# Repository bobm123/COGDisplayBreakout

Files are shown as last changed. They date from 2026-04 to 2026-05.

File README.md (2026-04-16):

# COG Display Breakout

This is a breakout board for the **ERC12864FSF-11** COG (Chip On Glass) LCD module, a 0.96", 128x64 pixel display using an ST7567 controller and 4-wire SPI an interface. The PCB routes the display's inputs from its 12-pin FFC cable to a breadboard-friendly 2.54mm pin header. It also exposes the backlight LED pins and provides a few discrete components for LCD module.

It was designed to have a  form factor (~27x27mm, 4 mounting holes, pin headers) to like the Adafruit [0.96" OLED module](https://www.adafruit.com/product/326) and similar 1" displays.

LCD technology differs from the OLED displays commonly found on display boards of this size. LCD should be daylight readable like e-paper, but with simpler hardware and software requirements. However, LCDs may need a backlight in low-light conditions, so the breakout includes connections display's built-in LED with an option for always on operation. Contrast control is through software.

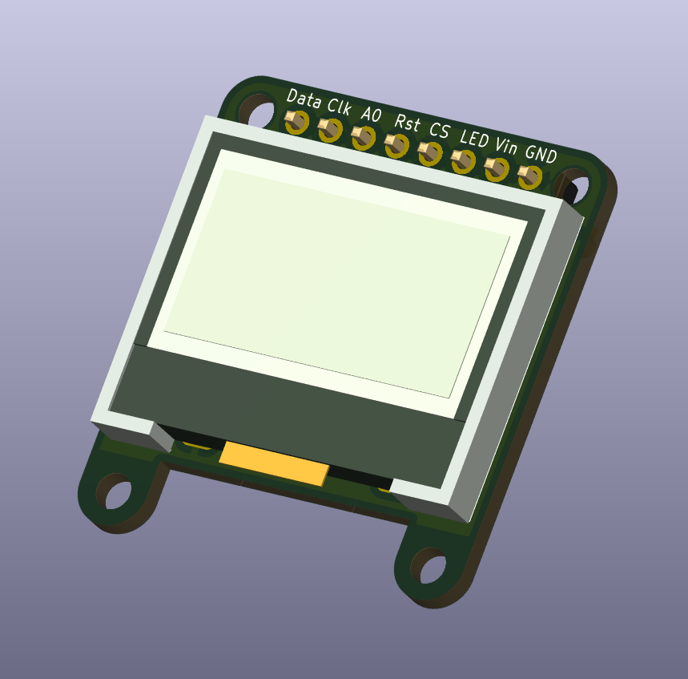
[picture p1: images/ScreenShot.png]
KiCad 3D render of the breakout board


## Specifications

| Parameter | Value |
|---|---|
| Display | [ERC12864FSF-11](https://www.buydisplay.com/0-96-inch-low-cost-white-128x64-graphic-cog-lcd-display-st7567-spi) (128x64, monochrome) |
| Controller | ST7567 |
| Interface | 4-wire SPI |
| Supply voltage | 3.3V only |
| Board size | ~27 x 27mm |
| Mounting | 4x M2 holes |

## Repository Structure

```
ArduinoCode/                             Example sketches for ESP32-C3
COGDisplayBreakout.pretty/               Custom footprint library
COGDisplayBreakout.3dmodels/             Custom 3D models
docs/                                    Datasheets, reference designs, tutorials
images/                                  Image assets
step/                                    3D models of the board and a small case
COGDisplayBreakout.kicad_sch             Schematic
COGDisplayBreakout.kicad_pcb             PCB layout
COGDisplayBreakout.kicad_sym             Custom symbol library
README.md
```

---

## Schematic and Board Layout

The KiCad 9 project files are at the repository root.

### Circuit Overview

The schematic connects the ERC12864FSF-11 display to an 8-pin SPI header (J1) with supporting passives:

**Header pinout (J1 - SPI_Header):**

| Pin | Signal | Description |
|-----|---|---|
| 1 | SDA | SPI data (MOSI) |
| 2 | SCL | SPI clock |
| 3 | A0 | Data/command select (DC) |
| 4 | /RST | Reset (active low) |
| 5 | /CS | Chip select (active low) |
| 6 | LED | LED control |
| 7 | VDD | +3.3V supply |
| 8 | GND | Ground |

**Passive components:**

| Ref | Value | Purpose |
|-----|---|---|
| R1 | 20R | Backlight LED current-limiting resistor |
| C1 | 10uF |  VDD bypass capacitor|
| C2 | 100nF | VDD bypass capacitor |
| C3 | 1uF | Charge pump capacitor (V0 to XV0) |
| C4 | 1uF | Charge pump capacitor (V0 to GND) |
| U1 | APX805S | Power-on reset IC for display /RST line |

The ST7567's built-in voltage booster generates the LCD bias voltage using external capacitors C3, and C4. No regulator or level shifting is included; the board is 3.3V only. Capacitors C1 and C2 are for decoupling. The R1 value was taken from the reference design, but for 10-20 mA LED current it should be about 200 Ohms.

The APX805S monitors VDD and holds the display /RST line low until power is stable, providing a clean power-on reset without requiring a GPIO pin from the host microcontroller. The /RST header pin (pin 4) is still available for external reset if needed.

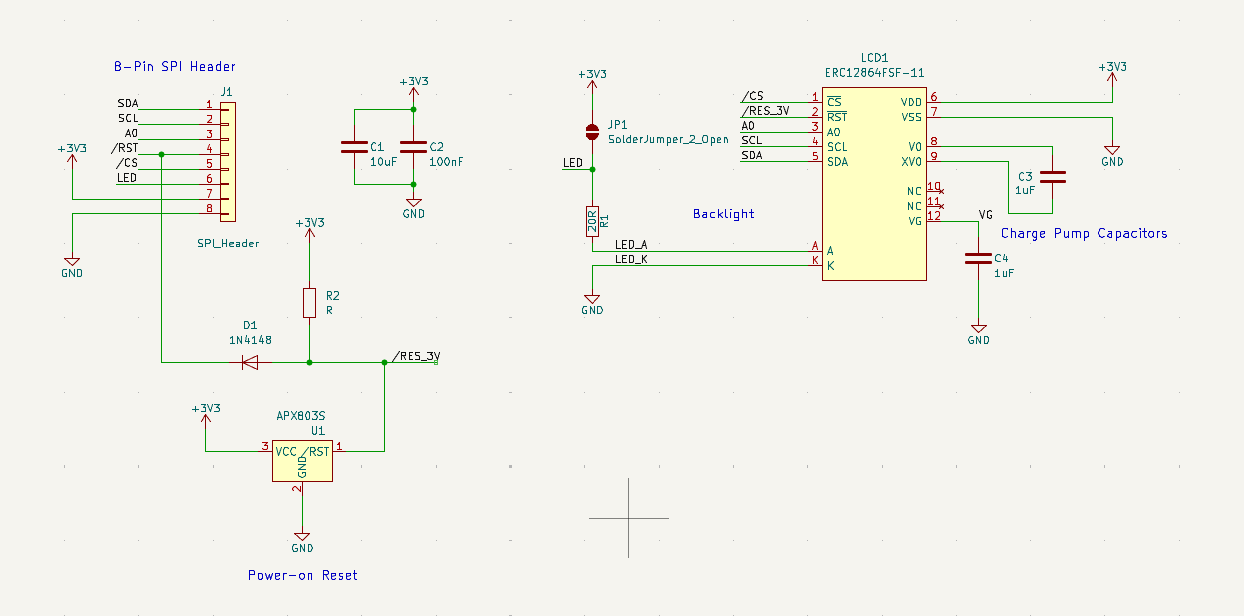
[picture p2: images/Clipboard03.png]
Breakout board schematic


### PCB

This is a 2-layer board, ~27x27mm. The display's 12-pin FFC cable (0.6mm pitch) is soldered directly to SMD pads on the back side. The display module mounts flat against the front by means of plastic mounting pins on the display case and the solder tabs for the backlight LED. Four M2 mounting holes at the corners matching similar OLED modules.

The display's 12-pin FFC cable is a non-standard 0.6mm pitch, so must be soldered directly to pads on the breakout PCB.

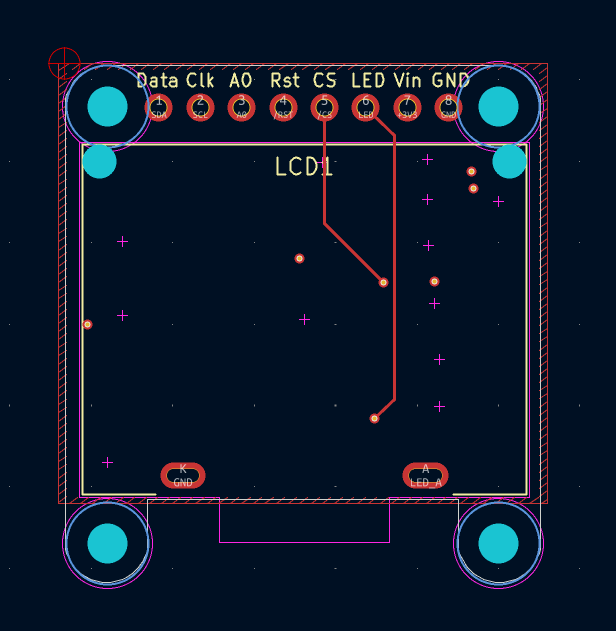
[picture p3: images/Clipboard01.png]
PCB - front

PCB Front (ground plane copper hidden)

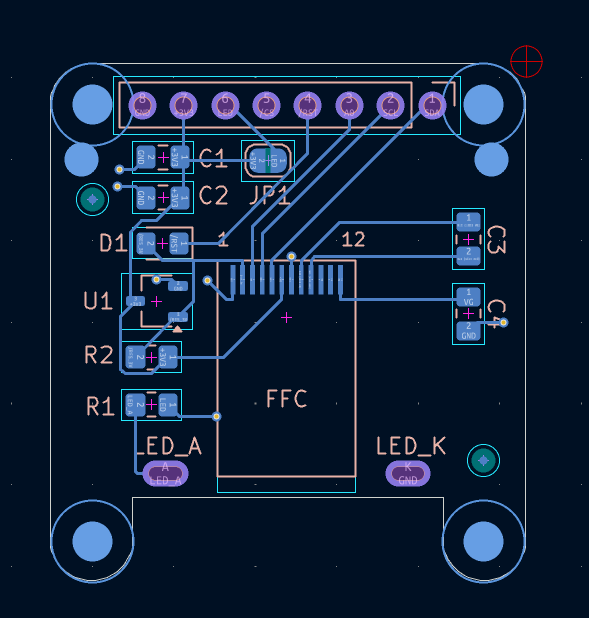
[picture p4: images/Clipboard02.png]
PCB - back

PCB Back

### Board Revisions

- **V0.1** (March 2026) - Initial prototype. Known issues: C1 wiring error, missing VG capacitor. See `AssemblyNotes.txt` for workarounds.

- **V0.2** (March 2026) - Fixed capacitor circuit. Known issue: backlight A/K pads swapped. See `AssemblyNotes.txt`.
Gerber files: V0.2 in `Gerbers20260323/`.

- **V1.0** (April 2026) - Fixed A/K pads and connected LED control to pin 6. See `AssemblyNotes.txt`.
Gerber files: V1.0 in `Gerbers20260403/`.

- **V1.1** (April 2026) - Added APX805S power-on reset IC for display /RST line. External reset connection via header pin 4 remains optional.
Gerbers sent to DigiKey RedBoard fab 2026-04-15.

---

## Custom ERC12864FSF-11 KiCad Library

The project includes a custom schematic symbol, PCB footprint, and 3D model for the ERC12864FSF-11 display module. These are in project-local libraries referenced via `sym-lib-table` and `fp-lib-table`.

### Schematic Symbol

**File:** `COGDisplayBreakout.kicad_sym`
**Symbol name:** `ERC12864FSF-11`

12-pin FFC cable (0.6mm pitch, 19mm long) plus 2 backlight pins.

| Pin | Name | Type | Description |
|-----|---|---|---|
| 1 | ~{CS} | Input | Chip select (active low) |
| 2 | ~{RST} | Input | Reset (active low) |
| 3 | A0 | Input | Data/command select |
| 4 | SCL | Input | SPI clock |
| 5 | SDA | Input | SPI data (MOSI) |
| 6 | VDD | Power | +3.3V supply |
| 7 | VSS | Power | Ground |
| 8 | V0 | Passive | Contrast voltage (booster output) |
| 9 | XV0 | Passive | Booster capacitor tap |
| 10 | NC | - | Not connected |
| 11 | NC | - | Not connected |
| 12 | VG | Passive | Negative voltage for LCD bias |
| A | A | Passive | Backlight LED anode |
| K | K | Passive | Backlight LED cathode |

Note: The backlight pins (A, K) are separate solder tabs on the display module, not part of the 12-pin FFC cable.

### PCB Footprint

**File:** `COGDisplayBreakout.pretty/ERC12864FSF-11_COG_LCD.kicad_mod`

There is a lot going on with this component's footprint:
- 12 SMD pads at 0.6mm pitch for direct-solder FFC cable connection
- Module outline on front silkscreen
- Back silkscreen shows how the FFC cable would wrap around
- 2 through-hole oval pads for backlight pins (A and K)
- Two NPT holes for case aliment studs
- An NPT oval slot to pass the FFC cable to the back of the PCB 

The 12 SMD pads are a bit longer to allow some play when wrapping the FFC cable around to the back. The pads and oval slot are positioned relative to the stud holes and backlight pins so the FFC cable end is centered on the pads. 

Unfortunately, there does not seem to be an FFC/FPC connector available in 12-pin, 6mm pitch so it must be soldered to the PCB. A piece of Kapton tape over the solder joins will provide a bit of strain relief and protection from shorts. 
  
### 3D Model

**Directory:** `COGDisplayBreakout.3dmodels/`

| File | Format | Description |
|---|---|---|
| `ERC12864FSF-11.step` | STEP | Solid body model for KiCad 3D viewer |
| `ERC12864FSF-11_COG_LCD.wrl` | VRML | Lightweight preview model |

The STEP model is referenced by the footprint and renders in KiCad's 3D viewer and to export the PCB with components as a 3D model.

---

## Arduino Code

Example sketches are in `ArduinoCode/`. The code should run on most modern Arduino board variants with sufficient pins and memory. The code currently targets the [**Adafruit QT Py ESP32-C3**](https://www.adafruit.com/product/5405) and uses the **U8g2** graphics library.

### Dependencies

- [U8g2](https://github.com/olikraus/u8g2) - Monochrome graphics library (handles ST7567 initialization, SPI transport, fonts, and drawing)
- SPI (built-in)

Install U8g2 via the Arduino IDE Library Manager.

### Pin Mapping (QT Py ESP32-C3 to breakout header)

| Display Signal | Header Pin | QT Py Pin | ESP32-C3 GPIO |
|---|---|---|---|
| SCL (clock) | 1 | SCK | 10 |
| SDA (data) | 2 | MO | 7 |
| A0 (DC) | 3 | MI* | 8 |
| /RST | 4 | APX805S on breakout | - |
| /CS | 5 | tied to GND | - |
| LED | 6 | A3 | - |
| GND | 1 | GND | - |
| VDD | 2 | 3V3 | - |

*The MISO pin is repurposed as GPIO since the ERC12864 does not provide data out.

### Sketches

Here are some Arduino sketches that can be run on a XIAO style board like Adafruit's QT Py ESP32-C3 with the connections shown above

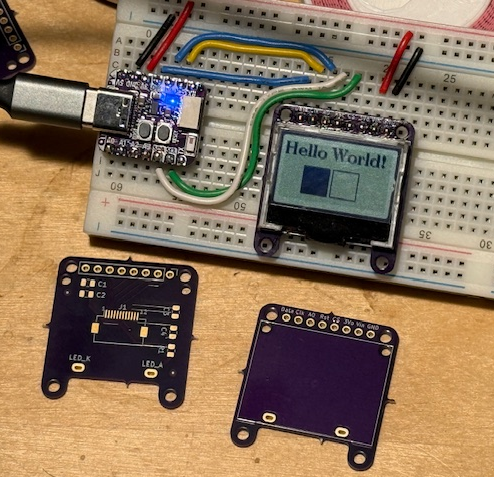
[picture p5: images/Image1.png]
Breadboard with QT Py ESP32-C3 and display running ERC12864_Hello


| Sketch | Description |
|---|---|
| `ERC12864_Hello/` | Minimal hello-world with text and simple graphics. Also blinks the QT Py's NeoPixel. |
| `ERC12864_SPIDemo/` | AI Port of the manufacturer's C tutorial. Cycles through text, graphics primitives, XBM bitmap, and test patterns. Includes commented-out contrast adjustment code for future button support. |
| `GraphicsTest/` | U8g2 graphics test suite (from the U8g2 examples, configured for this display). |
| `ScrollingText/` | U8g2 scrolling text demo (from the U8g2 examples, configured for this display). |

### U8g2 Constructor

All sketches use the same U8g2 constructor. Identifies the display module by part number and the SPI interface pins. See mappings above.

```cpp
U8G2_ST7565_ERC12864_ALT_F_4W_SW_SPI u8g2(U8G2_R0,
    /* clock=*/ 10, /* data=*/ 7, /* cs=*/ U8X8_PIN_NONE, /* dc=*/ 8, /* reset=*/ U8X8_PIN_NONE);
```

- `ERC12864_ALT` - contrast-improved variant for this display
- `_F_` - full framebuffer mode (~1KB RAM)
- `4W_SW_SPI` - 4-wire software SPI

The 4-wire HW variants of the U8g2 constructors are intended for the platform's native SPI interface: MOSI, MISO, clock and chip select. Since this device is write only the MISO pin is repurposed for A0 (Data/Command select). The 4-wire SW constructor is used to support this pin mapping but others are possible.

/CS is tied to GND on the breakout board, so the display is always selected and no GPIO is needed for chip select. If sharing the SPI bus with other devices, connect /CS to a GPIO pin and replace `U8X8_PIN_NONE` with that pin number in the constructor.

/RST is managed by the on-board APX805S power-on reset IC, so no GPIO is needed for reset. If external reset control is required, connect the /RST header pin to a GPIO and replace the reset `U8X8_PIN_NONE` with that pin number.

---

## Reference Documentation

Datasheets and reference material are in `docs/`:

- `ERC12864-11_Datasheet.pdf` - Display module datasheet
- `ST7567_V1.7.pdf` - Controller IC datasheet
- `ERC12864FSF-11_Display.md` - Display specifications summary
- `ERC12864FSF-11_SPI_Reference_Design.md` - Wiring guide and U8g2 examples
- `ERC12864-11_Tutorial/` - Manufacturer's C code tutorial and interface schematic

## Tools

- **KiCad 9** for schematic and PCB design
- **Arduino IDE** with ESP32 board support for firmware development
- **U8g2** library for display graphics

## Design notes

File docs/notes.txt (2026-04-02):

Link to .96 COG Display

Description

"ERC12864FSF-11 is 0.96 inch White background with 128x64 monochrome White pixels cog(chip on glass) lcd module,ST7567 controller,compact size,high contrast,wide operating temperature,wide view angle,white led backlight,fstn-lcd positive,fpc connection soldering type fpc connection,It supports 4-wire serial spi interface.

It's easily controlled by MCU such as 8051,PIC,AVR,ARDUINO,ARM and Raspberry Pi.It can be used in any embedded systems,industrial device,security,medical and hand-held equipment.

Of course, we wouldn't just leave you with a datasheet and a "good luck!".For 8051 microcontroller user,we prepared the detailed tutorial such as interfacing, demo code and Development Kit at the bottom of this page."

Black on White (on order):
https://www.buydisplay.com/0-96-inch-low-cost-white-128x64-graphic-cog-lcd-display-st7567-spi

White on Black:
https://www.buydisplay.com/0-96-inch-low-cost-black-128x64-graphic-cog-lcd-display-st7567-spi

White on Blue
https://www.buydisplay.com/0-96-inch-low-cost-blue-128x64-graphic-cog-lcd-display-st7567-spi

This will be fun for later, but they also have a SPI/I2C variant that might be more similar to
the Adafrui OLED units:
https://www.buydisplay.com/spi-small-0-96-inch-128x64-graphic-cog-lcd-display-module-for-smart-watch

See the ./ERC12864-10_Series/ directory for details
- has a 30 pin connector, needs bottom contact style connector
- slightly smaller case size
- can use 4-wire SPI or 2-wire I2C (TST5 pin to cuttable jumper)
- Backlight pins on ribbon cable

From Github U8g2 page:
https://github.com/olikraus/u8g2/wiki/u8x8setupcpp#st7567-erc12864

Controller "st7567", Display "erc12864"
U8X8_ST7567_ERC12864_4W_SW_SPI(clk, data, cs, dc [, reset])
U8X8_ST7567_ERC12864_4W_HW_SPI(cs, dc [, reset])
U8X8_ST7567_ERC12864_2ND_4W_HW_SPI(cs, dc [, reset])
U8X8_ST7567_ERC12864_3W_SW_SPI(clk, data, cs [, reset])
U8X8_ST7567_ERC12864_3W_HW_SPI(cs [, reset])
U8X8_ST7567_ERC12864_6800(d0, d1, d2, d3, d4, d5, d6, d7, enable, cs, dc [, reset])
U8X8_ST7567_ERC12864_8080(d0, d1, d2, d3, d4, d5, d6, d7, enable, cs, dc [, reset])

Actually, its the U8g2 library
U8G2_ST7565_ERC12864_ALT_1_4W_SW_SPI u8g2(U8G2_R0, /* clock=*/ 10, /* data=*/ 7, /* cs=*/ 6, /* dc=*/ 8, /* reset=*/ 5);

Docs
https://github.com/olikraus/u8g2/wiki/u8g2setupcpp#st7565-erc12864_alt
https://github.com/olikraus/u8g2/wiki/u8g2reference#carduino-example

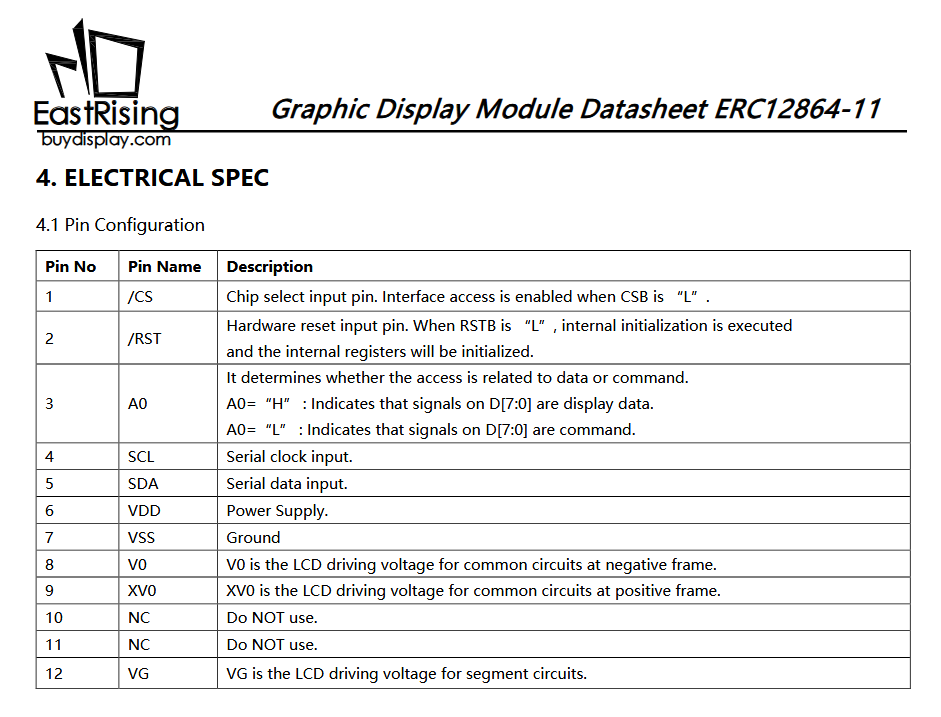
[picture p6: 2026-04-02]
docs/ERC12864-11-pinouts.png

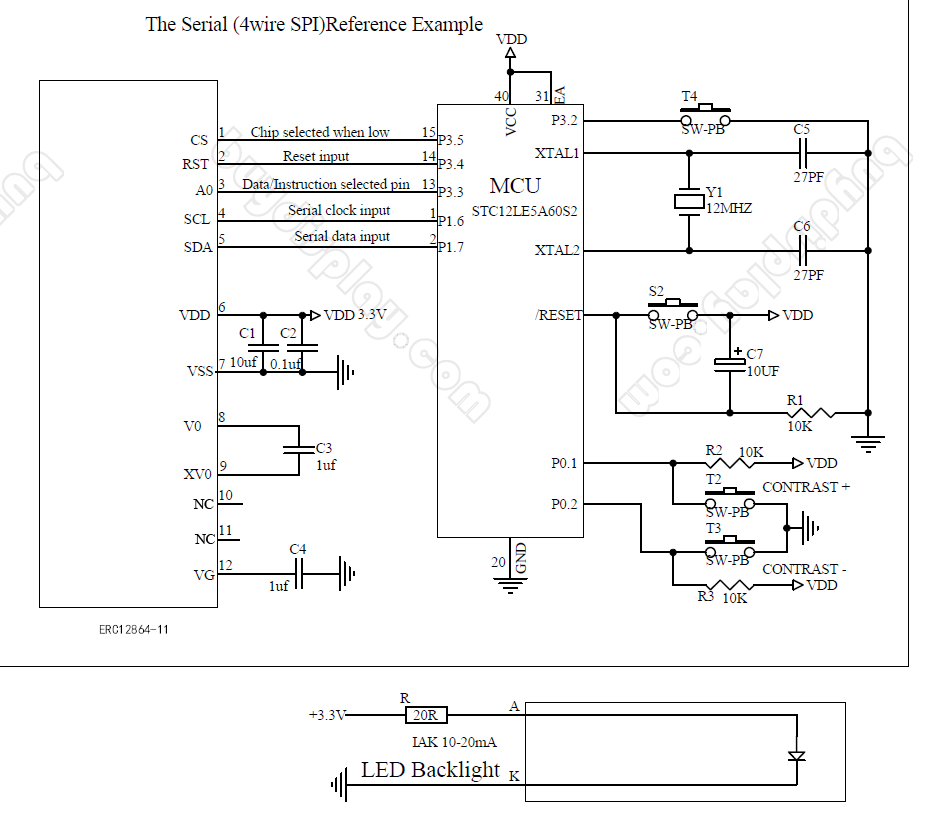
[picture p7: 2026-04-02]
docs/ERC12864-11_Tutorial/ReferenceDesign.png

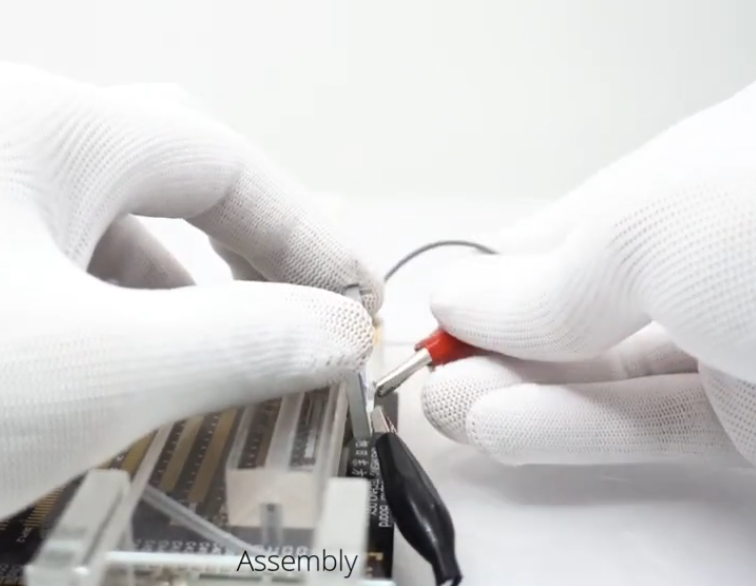
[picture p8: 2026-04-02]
docs/erc12864-11_LED_A_K.png

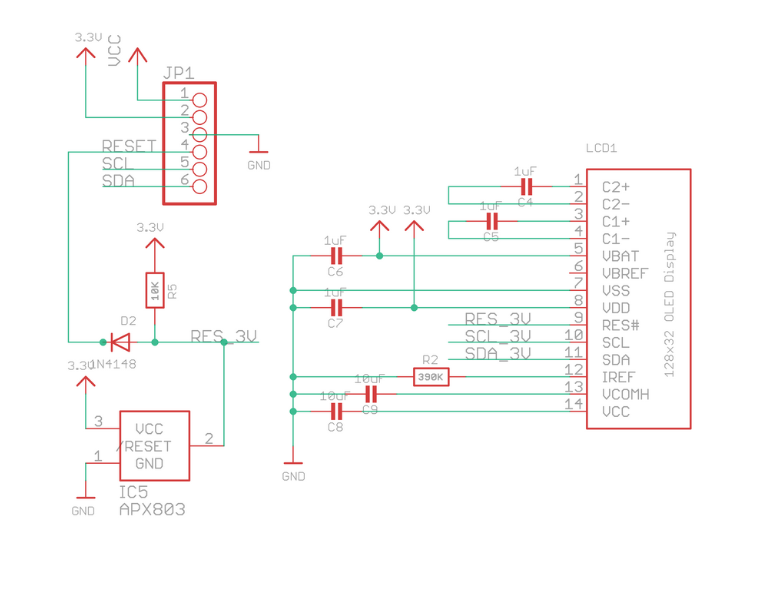
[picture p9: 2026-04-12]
docs/PO-ResetCircuit.png

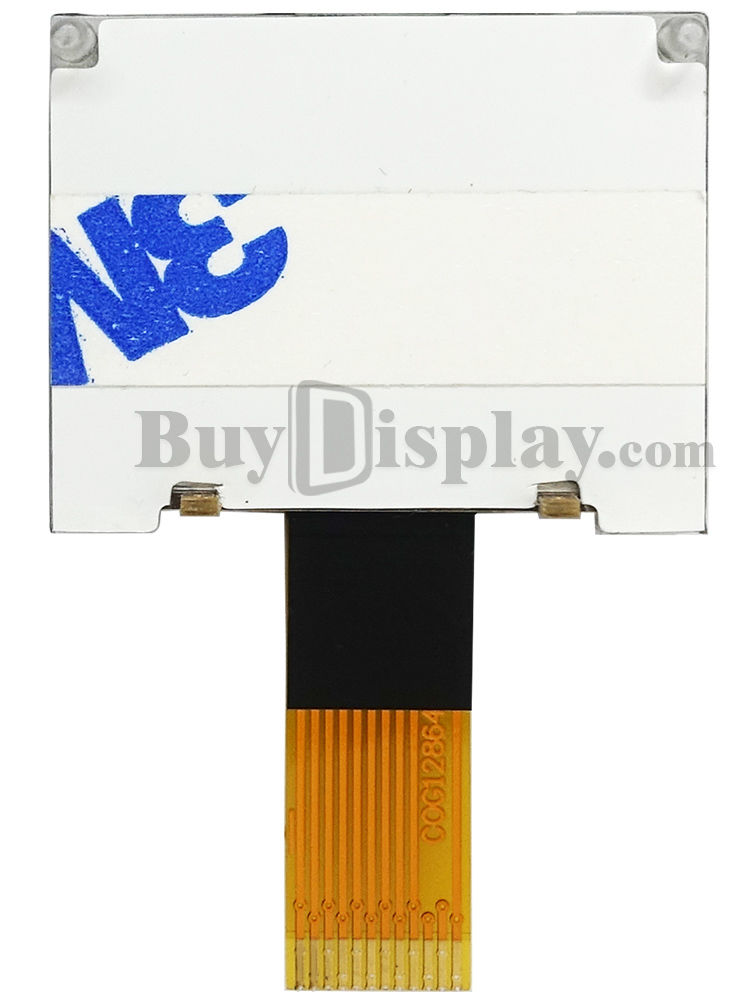
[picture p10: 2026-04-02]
docs/erc12864-11_backside.png

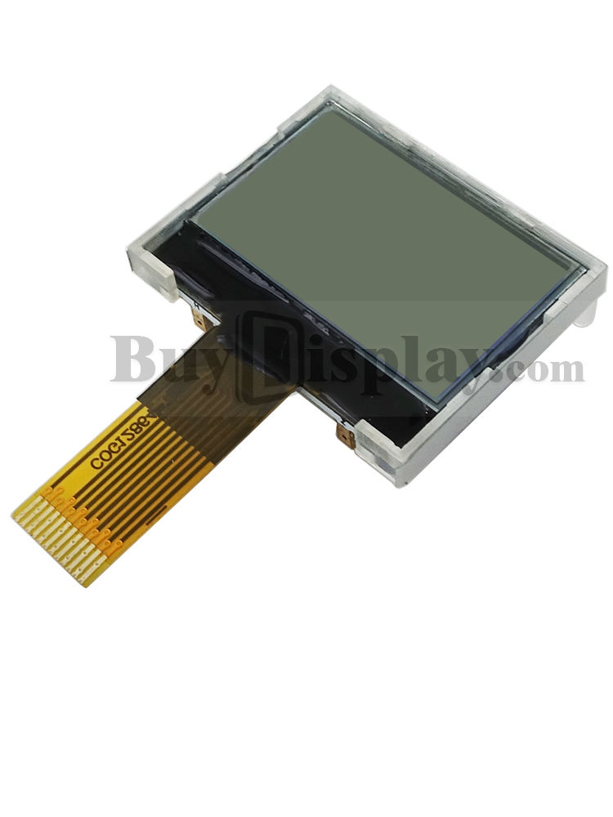
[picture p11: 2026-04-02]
docs/erc12864fsf-front.png

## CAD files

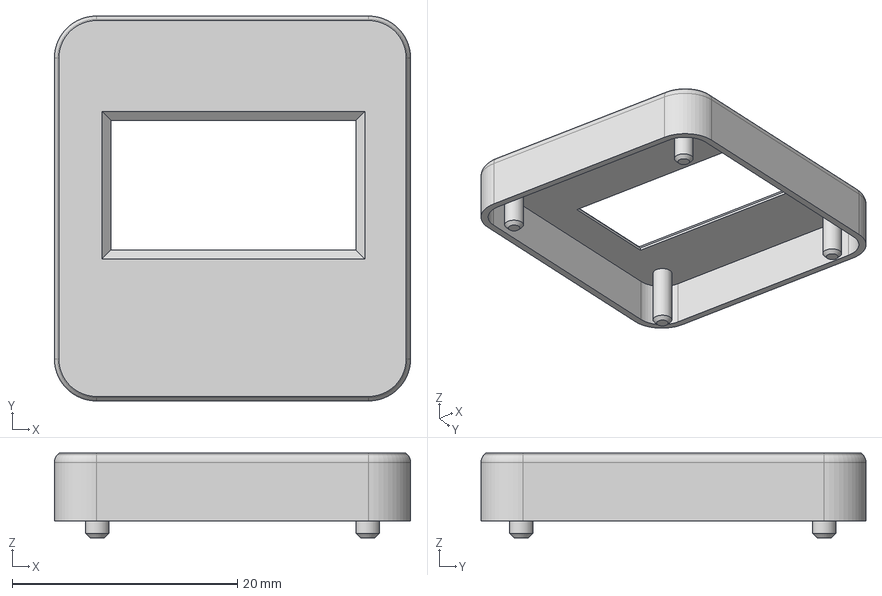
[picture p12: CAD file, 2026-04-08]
step/COGDisplayBreakout-Bezel.step
31.6 x 34.1 x 7.50 mm

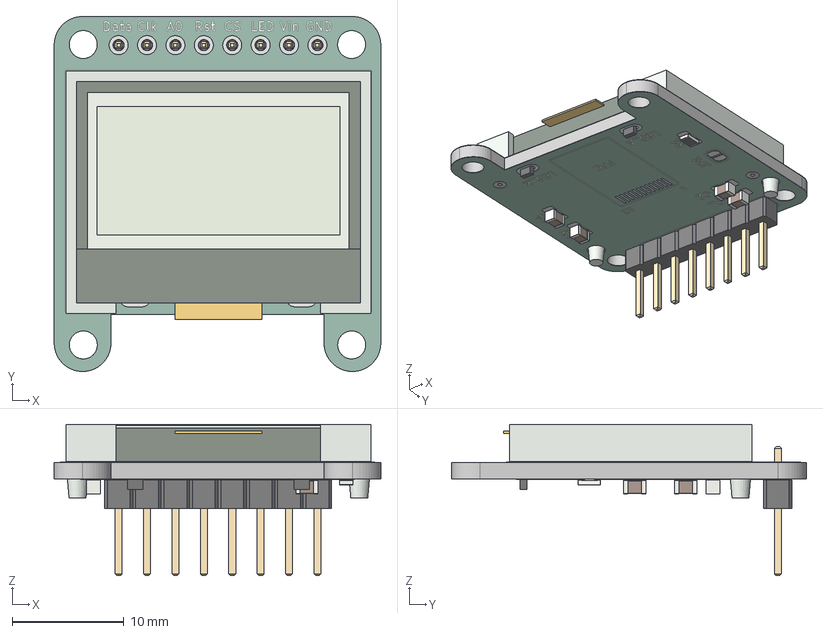
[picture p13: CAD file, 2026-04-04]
step/COGDisplayBreakout.step
29.2 x 31.8 x 13.5 mm
ERC12864FSF-11
C_0805_2012Metric x 4
PinHeader_1x08_P2.54mm_Vertical
R_0805_2012Metric
COGDisplayBreakout_copper
COGDisplayBreakout_pad
COGDisplayBreakout_via
COGDisplayBreakout_silkscreen x 2
COGDisplayBreakout_soldermask x 2
COGDisplayBreakout_PCB

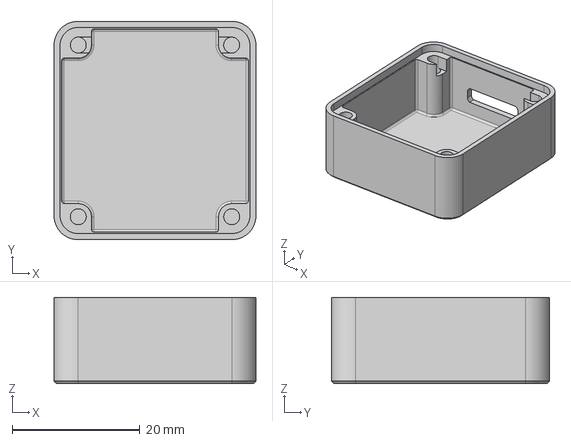
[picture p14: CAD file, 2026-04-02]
step/COGDisplayBreakout-Case.step
31.6 x 34.1 x 13.5 mm

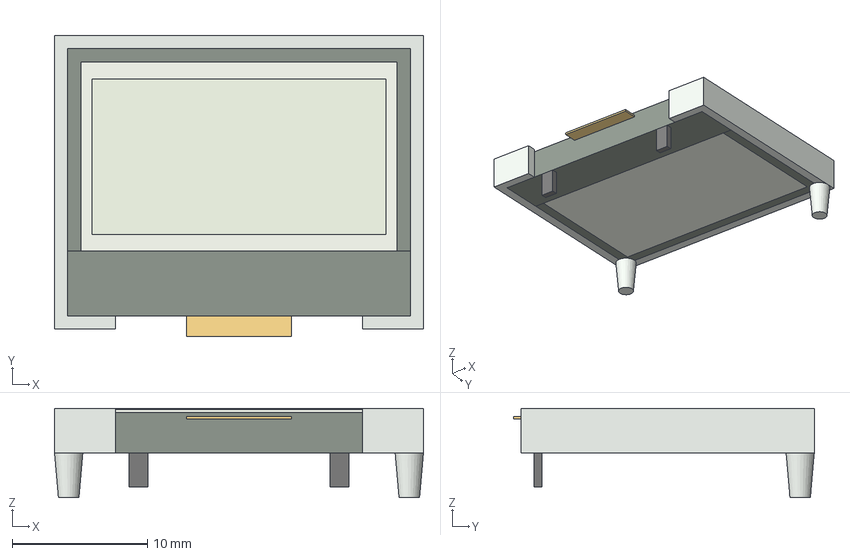
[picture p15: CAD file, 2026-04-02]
COGDisplayBreakout.3dmodels/ERC12864FSF-11.step
27.3 x 22.2 x 6.60 mm

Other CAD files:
step/COGDisplayBreakout-Bezel.stl

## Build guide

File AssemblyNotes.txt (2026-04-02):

Notes on V0.1 board sent to Fab on 3/3/2026
- Error in schematic has C1 (1uf) from V0 to ground. Leave this unpopulated
- Should have a second cap across 3.3 and gnd. C3/100nF is ok. if possible add a 10uF somewhere
- VG (currently unconnected, pin12 on connector) should have a 1uF cap to ground.
  -- possible remedy: 
    1) cut trace between C1 and C2. 
    2) cut trace From V0 to C2 pin 1 
    3) reconnect C2 pin 1 connector pin 12 (VG) with white wire  
- Same layout also sent to pcbway, back about the same time as oshpark board
- both board have wrong connector pitch! Unusable, D'oh!

Notes on V0.2 board, sent to Fab on 3/23/2026
- K and A swapped, avoid placing the resister
- Try bending tabs and insulate top 
- or file back the board and blue wire w/ 200R
- Should have used hand solder 0805 pads
- unconnected 3Vo pin, consider using this for LED on/off 
- check for an extra GND connection at V0 or VX0
- consider changing the 3Vo pin (unused) to a LED on function

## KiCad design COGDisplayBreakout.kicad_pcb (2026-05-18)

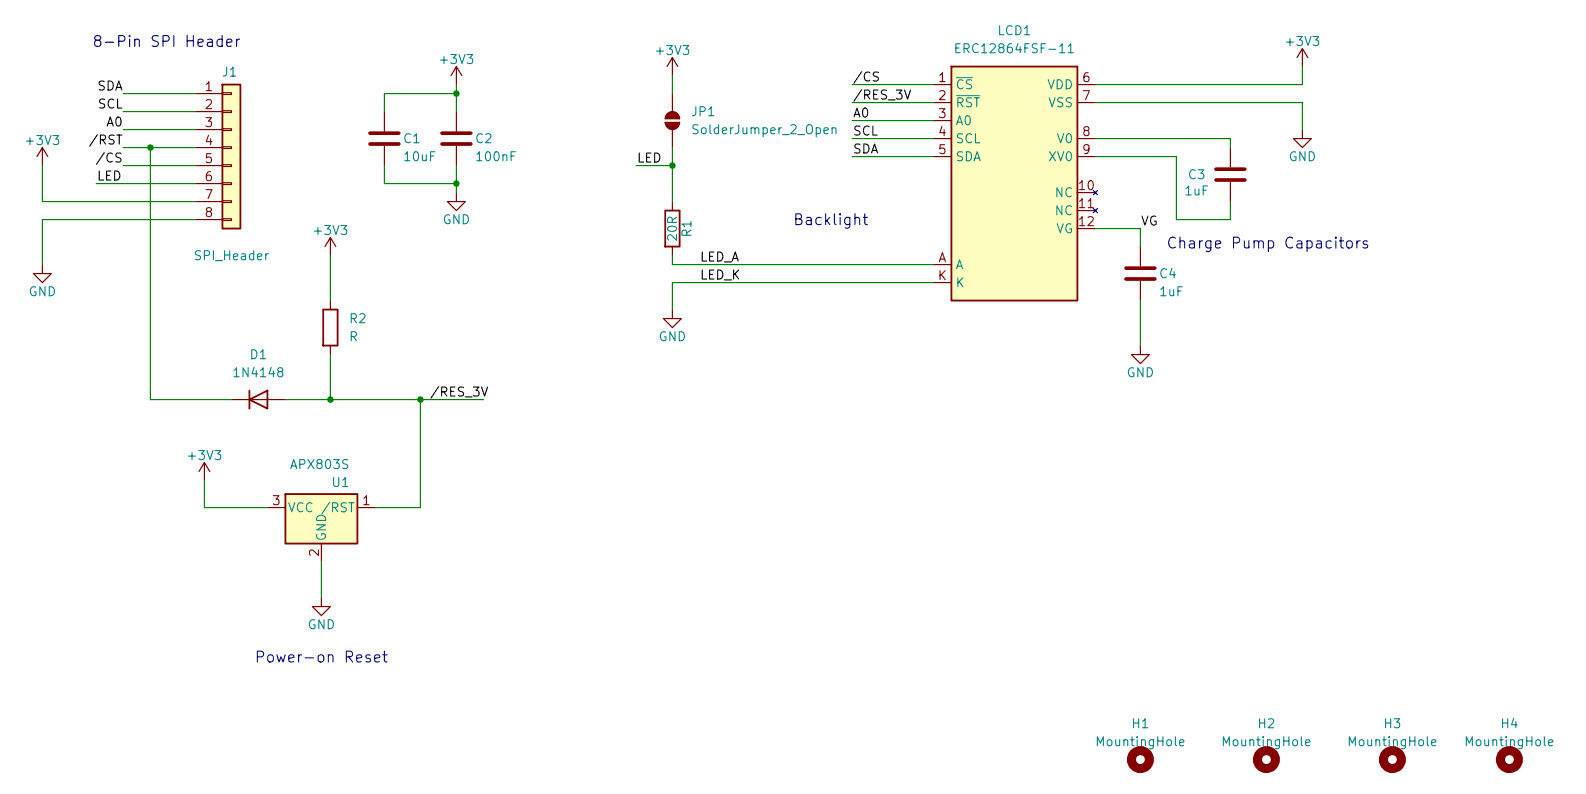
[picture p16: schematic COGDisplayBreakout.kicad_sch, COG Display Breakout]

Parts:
C1: 10uF; C_0805_2012Metric_Pad1.18x1.45mm_HandSolder
C2: 100nF; C_0805_2012Metric_Pad1.18x1.45mm_HandSolder
C3, C4: 1uF; C_0805_2012Metric_Pad1.18x1.45mm_HandSolder
D1: 1N4148; D_0805_2012Metric_Pad1.15x1.40mm_HandSolder
H1, H2, H3, H4: MountingHole; MountingHole_2.5mm
J1: SPI_Header; PinHeader_1x08_P2.54mm_Vertical
JP1: SolderJumper_2_Open; SolderJumper-2_P1.3mm_Open_RoundedPad1.0x1.5mm
LCD1: ERC12864FSF-11; ERC12864FSF-11_COG_LCD
R1: 20R; R_0805_2012Metric_Pad1.20x1.40mm_HandSolder
R2: R; R_0805_2012Metric_Pad1.20x1.40mm_HandSolder
U1: APX803S; TSOT-23

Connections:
+3V3: C1.1, C2.1, J1.7, JP1.2 (B), LCD1.6 (VDD), R2.1, U1.3 (VCC)
/A0: J1.3, LCD1.3 (A0)
/LED: J1.6, JP1.1 (A), R1.1
/LED_A: LCD1.A, R1.2
/SCL: J1.2, LCD1.4 (SCL)
/SDA: J1.1, LCD1.5 (SDA)
/VG: C4.1, LCD1.12 (VG)
//CS: J1.5, LCD1.1 (~CS)
//RES_3V: D1.2 (A), LCD1.2 (~RST), R2.2, U1.1 (/RST)
//RST: D1.1 (K), J1.4
GND: C1.2, C2.2, C4.2, J1.8, LCD1.7 (VSS), LCD1.K, U1.2 (GND)
unnamed: C3.1, LCD1.8 (V0)
unnamed: C3.2, LCD1.9 (XV0)

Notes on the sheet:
Charge Pump Capacitors
8-Pin SPI Header
Backlight
Power-on Reset

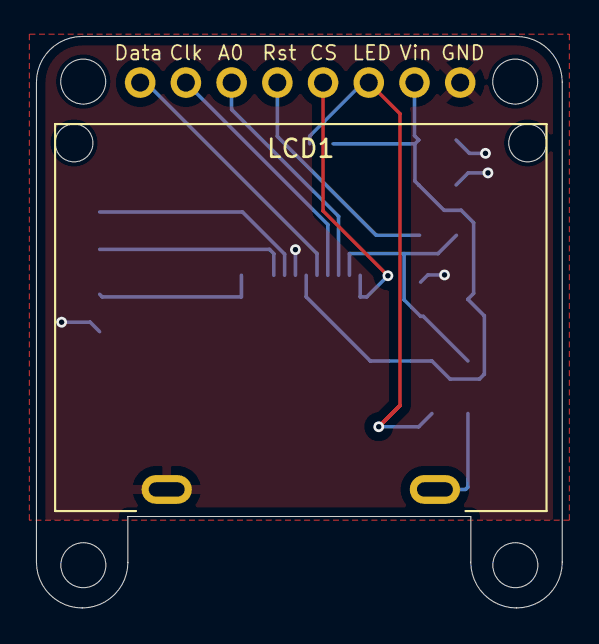
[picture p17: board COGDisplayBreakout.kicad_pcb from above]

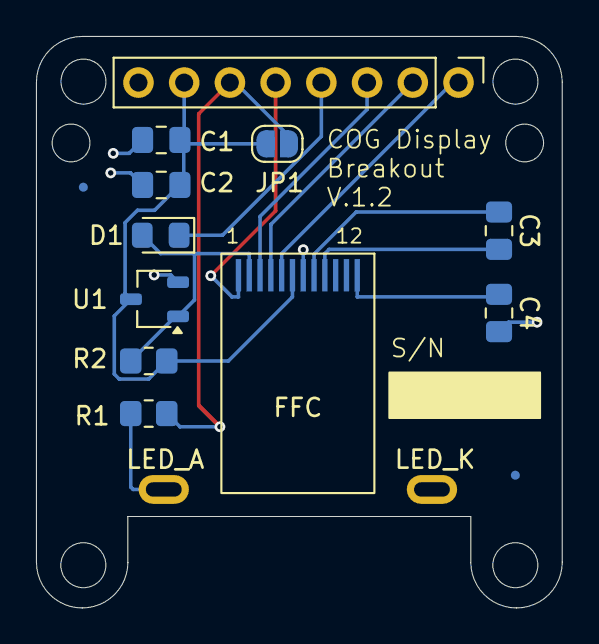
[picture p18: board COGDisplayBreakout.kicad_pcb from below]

Board: 2 copper layers, 29.2 x 31.8 mm, 17 parts (12 on the bottom side), 13 nets.

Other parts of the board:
FID1, FID2: FIDUCIAL""; Fiducial_0.5mm_Mask1.5mm

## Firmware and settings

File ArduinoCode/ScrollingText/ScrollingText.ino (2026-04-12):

/*

  ScrollingText.ino

  This will scroll text on the display. 
  Enable U8g2 16 bit mode (see FAQ) for larger text!

  Universal 8bit Graphics Library (https://github.com/olikraus/u8g2/)

  Copyright (c) 2016, olikraus@gmail.com
  All rights reserved.

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
  THIS SOFTWARE IS PROVIDED BY THE COPYRIGHT HOLDERS AND 
  CONTRIBUTORS "AS IS" AND ANY EXPRESS OR IMPLIED WARRANTIES, 
  INCLUDING, BUT NOT LIMITED TO, THE IMPLIED WARRANTIES OF 
  MERCHANTABILITY AND FITNESS FOR A PARTICULAR PURPOSE ARE 
  DISCLAIMED. IN NO EVENT SHALL THE COPYRIGHT HOLDER OR 
  CONTRIBUTORS BE LIABLE FOR ANY DIRECT, INDIRECT, INCIDENTAL, 
  SPECIAL, EXEMPLARY, OR CONSEQUENTIAL DAMAGES (INCLUDING, BUT 
  NOT LIMITED TO, PROCUREMENT OF SUBSTITUTE GOODS OR SERVICES; 
  LOSS OF USE, DATA, OR PROFITS; OR BUSINESS INTERRUPTION) HOWEVER 
  CAUSED AND ON ANY THEORY OF LIABILITY, WHETHER IN CONTRACT, 
  STRICT LIABILITY, OR TORT (INCLUDING NEGLIGENCE OR OTHERWISE) 
  ARISING IN ANY WAY OUT OF THE USE OF THIS SOFTWARE, EVEN IF 
  ADVISED OF THE POSSIBILITY OF SUCH DAMAGE.  

*/

#include <Arduino.h>
#include <U8g2lib.h>

#ifdef U8X8_HAVE_HW_SPI
#include <SPI.h>
#endif
#ifdef U8X8_HAVE_HW_I2C
#include <Wire.h>
#endif


/*
  U82glib Example Overview:
    Frame Buffer Examples: clearBuffer/sendBuffer. Fast, but may not work with all Arduino boards because of RAM consumption
    Page Buffer Examples: firstPage/nextPage. Less RAM usage, should work with all Arduino boards.
    U8x8 Text Only Example: No RAM usage, direct communication with display controller. No graphics, 8x8 Text only.
    
  This is a page buffer example.
  
*/

// Please UNCOMMENT one of the contructor lines below
// U8g2 Contructor List (Picture Loop Page Buffer)
// The complete list is available here: https://github.com/olikraus/u8g2/wiki/u8g2setupcpp
// Please update the pin numbers according to your setup. Use U8X8_PIN_NONE if the reset pin is not connected
// /CS is tied to GND on the breakout board (display always selected).
// If sharing the SPI bus with other devices, connect /CS to a GPIO and replace U8X8_PIN_NONE.
U8G2_ST7565_ERC12864_ALT_F_4W_SW_SPI u8g2(U8G2_R0, /* clock=*/ 10, /* data=*/ 7, /* cs=*/ U8X8_PIN_NONE, /* dc=*/ 8, /* reset=*/ 5);
//U8G2_NULL u8g2(U8G2_R0);	// null device, a 8x8 pixel display which does nothing
//U8G2_SSD1306_128X64_NONAME_1_4W_SW_SPI u8g2(U8G2_R0, /* clock=*/ 13, /* data=*/ 11, /* cs=*/ 10, /* dc=*/ 9, /* reset=*/ 8);
//U8G2_SSD1306_128X64_NONAME_1_4W_HW_SPI u8g2(U8G2_R0, /* cs=*/ 12, /* dc=*/ 4, /* reset=*/ 6);	// Arduboy (Production, Kickstarter Edition)
//U8G2_SSD1306_128X64_NONAME_1_4W_HW_SPI u8g2(U8G2_R0, /* cs=*/ 10, /* dc=*/ 9, /* reset=*/ 8);
//U8G2_SSD1306_128X64_NONAME_1_3W_SW_SPI u8g2(U8G2_R0, /* clock=*/ 13, /* data=*/ 11, /* cs=*/ 10, /* reset=*/ 8);
//U8G2_SSD1306_128X64_NONAME_1_3W_HW_SPI u8g2(U8G2_R0, /* cs=*/ 10, /* reset=*/ 8);
//U8G2_SSD1306_128X64_NONAME_1_HW_I2C u8g2(U8G2_R0, /* reset=*/ U8X8_PIN_NONE);
//U8G2_SSD1306_128X64_ALT0_1_HW_I2C u8g2(U8G2_R0, /* reset=*/ U8X8_PIN_NONE);   // same as the NONAME variant, but may solve the "every 2nd line skipped" problem
//U8G2_SSD1306_128X64_NONAME_1_SW_I2C u8g2(U8G2_R0, /* clock=*/ 13, /* data=*/ 11, /* reset=*/ 8);
//U8G2_SSD1306_128X64_NONAME_1_SW_I2C u8g2(U8G2_R0, /* clock=*/ SCL, /* data=*/ SDA, /* reset=*/ U8X8_PIN_NONE);   // All Boards without Reset of the Display
//U8G2_SSD1306_128X64_NONAME_1_SW_I2C u8g2(U8G2_R0, /* clock=*/ 16, /* data=*/ 17, /* reset=*/ U8X8_PIN_NONE);   // ESP32 Thing, pure SW emulated I2C
//U8G2_SSD1306_128X64_NONAME_1_HW_I2C u8g2(U8G2_R0, /* reset=*/ U8X8_PIN_NONE, /* clock=*/ 16, /* data=*/ 17);   // ESP32 Thing, HW I2C with pin remapping
//U8G2_SSD1306_128X64_NONAME_1_6800 u8g2(U8G2_R0, 13, 11, 2, 3, 4, 5, 6, A4, /*enable=*/ 7, /*cs=*/ 10, /*dc=*/ 9, /*reset=*/ 8);
//U8G2_SSD1306_128X64_NONAME_1_8080 u8g2(U8G2_R0, 13, 11, 2, 3, 4, 5, 6, A4, /*enable=*/ 7, /*cs=*/ 10, /*dc=*/ 9, /*reset=*/ 8);
//U8G2_SSD1306_128X64_VCOMH0_1_4W_HW_SPI u8g2(U8G2_R0, /* cs=*/ 10, /* dc=*/ 9, /* reset=*/ 8);	// same as the NONAME variant, but maximizes setContrast() range
//U8G2_SSD1306_128X64_ALT0_1_4W_HW_SPI u8g2(U8G2_R0, /* cs=*/ 10, /* dc=*/ 9, /* reset=*/ 8);	// same as the NONAME variant, but may solve the "every 2nd line skipped" problem
//U8G2_SSD1306_102X64_EA_OLEDS102_1_4W_HW_SPI u8g2(U8G2_R0, /* cs=*/ 10, /* dc=*/ 9, /* reset=*/ 8);	// same as the NONAME variant, but may solve the "every 2nd line skipped" problem
//U8G2_SSD1312_128X64_NONAME_1_4W_SW_SPI u8g2(U8G2_R0, /* clock=*/ 13, /* data=*/ 11, /* cs=*/ 10, /* dc=*/ 9, /* reset=*/ 8);
//U8G2_SSD1312_128X64_NONAME_1_SW_I2C u8g2(U8G2_R0, /* clock=*/ SCL, /* data=*/ SDA, /* reset=*/ 8);
//U8G2_SSD1312_128X64_NONAME_1_HW_I2C u8g2(U8G2_R0, /* reset=*/ 8);
//U8G2_SSD1312_120X28_1_4W_SW_SPI u8g2(U8G2_R0, /* clock=*/ 13, /* data=*/ 11, /* cs=*/ 10, /* dc=*/ 9, /* reset=*/ 8);
//U8G2_SSD1312_120X28_1_SW_I2C u8g2(U8G2_R0, /* clock=*/ SCL, /* data=*/ SDA, /* reset=*/ 8);
//U8G2_SSD1312_120X28_1_HW_I2C u8g2(U8G2_R0, /* reset=*/ 8);
//U8G2_SH1106_128X64_NONAME_1_4W_HW_SPI u8g2(U8G2_R0, /* cs=*/ 10, /* dc=*/ 9, /* reset=*/ 8);
//U8G2_SH1106_128X64_NONAME_1_HW_I2C u8g2(U8G2_R0, /* reset=*/ U8X8_PIN_NONE);
//U8G2_SH1106_128X64_VCOMH0_1_4W_HW_SPI u8g2(U8G2_R0, /* cs=*/ 10, /* dc=*/ 9, /* reset=*/ 8);		// same as the NONAME variant, but maximizes setContrast() range
//U8G2_SH1106_128X64_WINSTAR_1_4W_HW_SPI u8g2(U8G2_R0, /* cs=*/ 10, /* dc=*/ 9, /* reset=*/ 8);		// same as the NONAME variant, but uses updated SH1106 init sequence
//U8G2_SH1106_128X32_VISIONOX_1_HW_I2C u8g2(U8G2_R0, /* reset=*/ U8X8_PIN_NONE); 
//U8G2_SH1106_128X32_VISIONOX_1_4W_HW_SPI u8g2(U8G2_R0, /* cs=*/ 10, /* dc=*/ 9, /* reset=*/ 8);
//U8G2_SH1106_72X40_WISE_1_4W_HW_SPI u8g2(U8G2_R0, /* cs=*/ 10, /* dc=*/ 9, /* reset=*/ 8);
//U8G2_SH1107_64X128_1_4W_HW_SPI u8g2(U8G2_R0, /* cs=*/ 10, /* dc=*/ 9, /* reset=*/ 8);
//U8G2_SH1107_128X128_1_4W_HW_SPI u8g2(U8G2_R0, /* cs=*/ 10, /* dc=*/ 9, /* reset=*/ 8);
//U8G2_SH1107_128X128_1_HW_I2C u8g2(U8G2_R0, /* reset=*/ 8);
//U8G2_SH1107_128X80_1_HW_I2C u8g2(U8G2_R0, /* reset=*/ 8);
//U8G2_SH1107_PIMORONI_128X128_1_HW_I2C u8g2(U8G2_R0, /* reset=*/ 8);
//U8G2_SH1107_SEEED_128X128_1_SW_I2C u8g2(U8G2_R0, /* clock=*/ SCL, /* data=*/ SDA, /* reset=*/ U8X8_PIN_NONE);
//U8G2_SH1107_SEEED_128X128_1_HW_I2C u8g2(U8G2_R0, /* reset=*/ U8X8_PIN_NONE);
//U8G2_SH1107_SEEED_96X96_1_4W_HW_SPI u8g2(U8G2_R0, /* cs=*/ 10, /* dc=*/ 9, /* reset=*/ 8);
//U8G2_SH1107_HJR_OEL1M0201_96X96_1_4W_HW_SPI u8g2(U8G2_R0, /* cs=*/ 10, /* dc=*/ 9, /* reset=*/ 8);
//U8G2_SH1107_TK078F288_80X128_1_4W_HW_SPI u8g2(U8G2_R0, /* cs=*/ 10, /* dc=*/ 9, /* reset=*/ 8);
//U8G2_SH1108_128X160_1_4W_HW_SPI u8g2(U8G2_R0, /* cs=*/ 10, /* dc=*/ 9, /* reset=*/ 8);
//U8G2_CH1120_128X160_1_4W_HW_SPI u8g2(U8G2_R0, /* cs=*/ 10, /* dc=*/ 9, /* reset=*/ 8);
//U8G2_SH1108_160X160_1_4W_HW_SPI u8g2(U8G2_R0, /* cs=*/ 10, /* dc=*/ 9, /* reset=*/ 8);
//U8G2_SH1122_256X64_1_4W_HW_SPI u8g2(U8G2_R0, /* cs=*/ 10, /* dc=*/ 9, /* reset=*/ 8);				// Enable U8G2_16BIT in u8g2.h
//U8G2_SH1122_256X64_1_4W_SW_SPI u8g2(U8G2_R0, /* clock=*/ 13, /* data=*/ 11, /* cs=*/ 10, /* dc=*/ 9, /* reset=*/ 8);        // Enable U8G2_16BIT in u8g2.h
//U8G2_SSD1306_128X32_UNIVISION_1_SW_I2C u8g2(U8G2_R0, /* clock=*/ 21, /* data=*/ 20, /* reset=*/ U8X8_PIN_NONE);   // Adafruit Feather M0 Basic Proto + FeatherWing OLED
//U8G2_SSD1306_128X32_UNIVISION_1_SW_I2C u8g2(U8G2_R0, /* clock=*/ SCL, /* data=*/ SDA, /* reset=*/ U8X8_PIN_NONE);   // Adafruit Feather ESP8266/32u4 Boards + FeatherWing OLED
//U8G2_SSD1306_128X32_UNIVISION_1_HW_I2C u8g2(U8G2_R0, /* reset=*/ U8X8_PIN_NONE);   // Adafruit ESP8266/32u4/ARM Boards + FeatherWing OLED
//U8G2_SSD1306_128X32_UNIVISION_1_HW_I2C u8g2(U8G2_R0, /* reset=*/ U8X8_PIN_NONE, /* clock=*/ SCL, /* data=*/ SDA);   // pin remapping with ESP8266 HW I2C
//U8G2_SSD1306_128X32_WINSTAR_1_HW_I2C u8g2(U8G2_R0, /* reset=*/ U8X8_PIN_NONE, /* clock=*/ SCL, /* data=*/ SDA);   // pin remapping with ESP8266 HW I2C
//U8G2_SSD1306_64X48_ER_1_HW_I2C u8g2(U8G2_R0, /* reset=*/ U8X8_PIN_NONE);   // EastRising 0.66" OLED breakout board, Uno: A4=SDA, A5=SCL, 5V powered
//U8G2_SSD1306_48X64_WINSTAR_1_HW_I2C u8g2(U8G2_R0, /* reset=*/ U8X8_PIN_NONE);   
//U8G2_SSD1306_64X32_NONAME_1_HW_I2C u8g2(U8G2_R0, /* reset=*/ U8X8_PIN_NONE);
//U8G2_SSD1306_64X32_1F_1_HW_I2C u8g2(U8G2_R0, /* reset=*/ U8X8_PIN_NONE);
//U8G2_SSD1306_96X16_ER_1_HW_I2C u8g2(U8G2_R0, /* reset=*/ U8X8_PIN_NONE);   // EastRising 0.69" OLED 
//U8G2_SSD1306_72X40_ER_1_HW_I2C u8g2(U8G2_R0, /* reset=*/ U8X8_PIN_NONE);   // EastRising 0.42" OLED 
//U8G2_SSD1306_96X40_1_HW_I2C u8g2(U8G2_R0, /* reset=*/ U8X8_PIN_NONE);
//U8G2_SSD1306_96X39_1_HW_I2C u8g2(U8G2_R0, /* reset=*/ U8X8_PIN_NONE);
//U8G2_SSD1322_240X128_1_4W_SW_SPI u8g2(U8G2_R0, /* clock=*/ 13, /* data=*/ 11, /* cs=*/ 10, /* dc=*/ 9, /* reset=*/ 8);
//U8G2_SSD1322_TOPWIN_240X128_1_4W_SW_SPI u8g2(U8G2_R0, /* clock=*/ 13, /* data=*/ 11, /* cs=*/ 10, /* dc=*/ 9, /* reset=*/ 8);
//U8G2_SSD1322_NHD_256X64_1_4W_SW_SPI u8g2(U8G2_R0, /* clock=*/ 13, /* data=*/ 11, /* cs=*/ 10, /* dc=*/ 9, /* reset=*/ 8);	// Enable U8G2_16BIT in u8g2.h
//U8G2_SSD1322_NHD_256X64_1_4W_HW_SPI u8g2(U8G2_R0, /* cs=*/ 10, /* dc=*/ 9, /* reset=*/ 8);	// Enable U8G2_16BIT in u8g2.h
//U8G2_SSD1322_ZJY_256X64_1_4W_SW_SPI u8g2(U8G2_R0, /* clock=*/ 13, /* data=*/ 11, /* cs=*/ 10, /* dc=*/ 9, /* reset=*/ 8);	// Enable U8G2_16BIT in u8g2.h
//U8G2_SSD1322_ZJY_256X64_1_4W_HW_SPI u8g2(U8G2_R0, /* cs=*/ 10, /* dc=*/ 9, /* reset=*/ 8);	// Enable U8G2_16BIT in u8g2.h
//U8G2_SSD1362_256X64_1_4W_SW_SPI u8g2(U8G2_R0, /* clock=*/ 13, /* data=*/ 11, /* cs=*/ 10, /* dc=*/ 9, /* reset=*/ 8);	// Enable U8G2_16BIT in u8g2.h
//U8G2_SSD1362_256X64_1_4W_HW_SPI u8g2(U8G2_R0, /* cs=*/ 10, /* dc=*/ 9, /* reset=*/ 8);	// Enable U8G2_16BIT in u8g2.h
//U8G2_SSD1362_206X36_1_4W_SW_SPI u8g2(U8G2_R0, /* clock=*/ 13, /* data=*/ 11, /* cs=*/ 10, /* dc=*/ 9, /* reset=*/ 8);
//U8G2_SSD1362_206X36_1_4W_HW_SPI u8g2(U8G2_R0, /* cs=*/ 10, /* dc=*/ 9, /* reset=*/ 8);
//U8G2_SSD1363_256X128_1_4W_SW_SPI u8g2(U8G2_R0, /* clock=*/ 13, /* data=*/ 11, /* cs=*/ 10, /* dc=*/ 9, /* reset=*/ 8);	// Enable U8G2_16BIT in u8g2.h
//U8G2_SSD1363_256X128_1_4W_HW_SPI u8g2(U8G2_R0, /* cs=*/ 10, /* dc=*/ 9, /* reset=*/ 8);	// Enable U8G2_16BIT in u8g2.h
//U8G2_SSD1322_NHD_128X64_1_4W_SW_SPI u8g2(U8G2_R0, /* clock=*/ 13, /* data=*/ 11, /* cs=*/ 10, /* dc=*/ 9, /* reset=*/ 8);
//U8G2_SSD1322_NHD_128X64_1_4W_HW_SPI u8g2(U8G2_R0, /* cs=*/ 10, /* dc=*/ 9, /* reset=*/ 8);
//U8G2_SSD1325_NHD_128X64_1_4W_SW_SPI u8g2(U8G2_R0, /* clock=*/ 13, /* data=*/ 11, /* cs=*/ 10, /* dc=*/ 9, /* reset=*/ 8);
//U8G2_SSD1325_NHD_128X64_1_4W_HW_SPI u8g2(U8G2_R0, /* cs=*/ 10, /* dc=*/ 9, /* reset=*/ 8);
//U8G2_SSD0323_OS128064_1_4W_SW_SPI u8g2(U8G2_R0, /* clock=*/ 13, /* data=*/ 11, /* cs=*/ 10, /* dc=*/ 9, /* reset=*/ 8);
//U8G2_SSD0323_OS128064_1_4W_HW_SPI u8g2(U8G2_R0, /* cs=*/ 10, /* dc=*/ 9, /* reset=*/ 8);
//U8G2_SSD1326_ER_256X32_1_4W_SW_SPI u8g2(U8G2_R0, /* clock=*/ 13, /* data=*/ 11, /* cs=*/ 10, /* dc=*/ 9, /* reset=*/ 8);         // experimental driver for ER-OLED018-1
//U8G2_SSD1327_SEEED_96X96_1_SW_I2C u8g2(U8G2_R0, /* clock=*/ SCL, /* data=*/ SDA, /* reset=*/ U8X8_PIN_NONE);	// Seeedstudio Grove OLED 96x96
//U8G2_SSD1327_SEEED_96X96_1_HW_I2C u8g2(U8G2_R0, /* reset=*/ U8X8_PIN_NONE);	// Seeedstudio Grove OLED 96x96
//U8G2_SSD1327_EA_W128128_1_4W_SW_SPI u8g2(U8G2_R0, /* clock=*/ 13, /* data=*/ 11, /* cs=*/ 10, /* dc=*/ 9, /* reset=*/ 8);
//U8G2_SSD1327_EA_W128128_1_4W_HW_SPI u8g2(U8G2_R0, /* cs=*/ 10, /* dc=*/ 9, /* reset=*/ 8);
//U8G2_SSD1327_EA_W128128_1_SW_I2C u8g2(U8G2_R0, /* clock=*/ 5, /* data=*/ 4, /* reset=*/ U8X8_PIN_NONE);
//U8G2_SSD1327_EA_W128128_1_HW_I2C u8g2(U8G2_R0, /* reset=*/ U8X8_PIN_NONE); /* Uno: A4=SDA, A5=SCL, add "u8g2.setBusClock(400000);" into setup() for speedup if possible */
//U8G2_SSD1327_MIDAS_128X128_1_4W_SW_SPI u8g2(U8G2_R0, /* clock=*/ 13, /* data=*/ 11, /* cs=*/ 10, /* dc=*/ 9, /* reset=*/ 8);
//U8G2_SSD1327_MIDAS_128X128_1_4W_HW_SPI u8g2(U8G2_R0, /* cs=*/ 10, /* dc=*/ 9, /* reset=*/ 8);
//U8G2_SSD1327_MIDAS_128X128_1_HW_I2C u8g2(U8G2_R0, /* reset=*/ U8X8_PIN_NONE); /* Uno: A4=SDA, A5=SCL, add "u8g2.setBusClock(400000);" into setup() for speedup if possible */
//U8G2_SSD1327_ZJY_128X128_1_4W_SW_SPI u8g2(U8G2_R0, /* clock=*/ 13, /* data=*/ 11, /* cs=*/ 10, /* dc=*/ 9, /* reset=*/ 8);
//U8G2_SSD1327_ZJY_128X128_1_4W_HW_SPI u8g2(U8G2_R0, /* cs=*/ 10, /* dc=*/ 9, /* reset=*/ 8);
//U8G2_SSD1327_ZJY_128X128_1_HW_I2C u8g2(U8G2_R0, /* reset=*/ U8X8_PIN_NONE); /* Uno: A4=SDA, A5=SCL, add "u8g2.setBusClock(400000);" into setup() for speedup if possible */
//U8G2_SSD1327_WS_128X128_1_4W_SW_SPI u8g2(U8G2_R0, /* clock=*/ 13, /* data=*/ 11, /* cs=*/ 10, /* dc=*/ 9, /* reset=*/ 8);
//U8G2_SSD1327_WS_128X128_1_4W_HW_SPI u8g2(U8G2_R0, /* cs=*/ 10, /* dc=*/ 9, /* reset=*/ 8);
//U8G2_SSD1327_VISIONOX_128X96_1_4W_SW_SPI u8g2(U8G2_R0, /* clock=*/ 13, /* data=*/ 11, /* cs=*/ 10, /* dc=*/ 9, /* reset=*/ 8);
//U8G2_SSD1327_VISIONOX_128X96_1_4W_HW_SPI u8g2(U8G2_R0, /* cs=*/ 10, /* dc=*/ 9, /* reset=*/ 8);
//U8G2_SSD1329_128X96_NONAME_1_4W_SW_SPI u8g2(U8G2_R0, /* clock=*/ 13, /* data=*/ 11, /* cs=*/ 10, /* dc=*/ 9, /* reset=*/ 8);
//U8G2_SSD1329_128X96_NONAME_1_4W_HW_SPI u8g2(U8G2_R0, /* cs=*/ 10, /* dc=*/ 9, /* reset=*/ 8);
//U8G2_SSD1329_96X96_NONAME_1_4W_SW_SPI u8g2(U8G2_R0, /* clock=*/ 13, /* data=*/ 11, /* cs=*/ 10, /* dc=*/ 9, /* reset=*/ 8);
//U8G2_SSD1329_96X96_NONAME_1_4W_HW_SPI u8g2(U8G2_R0, /* cs=*/ 10, /* dc=*/ 9, /* reset=*/ 8);
//U8G2_SSD1329_96X96_NONAME_1_4W_HW_SPI u8g2(U8G2_R0, /* cs=*/ A4, /* dc=*/ A2, /* reset=*/ U8X8_PIN_NONE); //  Adafruit Feather 32u4 Basic Proto
//U8G2_SSD1305_128X32_NONAME_1_4W_SW_SPI u8g2(U8G2_R0, /* clock=*/ 13, /* data=*/ 11, /* cs=*/ 10, /* dc=*/ 9, /* reset=*/ 8);
//U8G2_SSD1305_128X32_NONAME_1_4W_HW_SPI u8g2(U8G2_R0, /* cs=*/ 10, /* dc=*/ 9, /* reset=*/ 8);
//U8G2_SSD1305_128X32_ADAFRUIT_1_4W_SW_SPI u8g2(U8G2_R0, /* clock=*/ 13, /* data=*/ 11, /* cs=*/ 10, /* dc=*/ 9, /* reset=*/ 8);
//U8G2_SSD1305_128X32_ADAFRUIT_1_4W_HW_SPI u8g2(U8G2_R0, /* cs=*/ 10, /* dc=*/ 9, /* reset=*/ 8);
//U8G2_SSD1305_128X64_ADAFRUIT_1_4W_SW_SPI u8g2(U8G2_R0, /* clock=*/ 13, /* data=*/ 11, /* cs=*/ 10, /* dc=*/ 9, /* reset=*/ 8);
//U8G2_SSD1305_128X64_ADAFRUIT_1_4W_HW_SPI u8g2(U8G2_R0, /* cs=*/ 10, /* dc=*/ 9, /* reset=*/ 8);
//U8G2_SSD1305_128X64_RAYSTAR_1_4W_SW_SPI u8g2(U8G2_R0, /* clock=*/ 13, /* data=*/ 11, /* cs=*/ 10, /* dc=*/ 9, /* reset=*/ 8);
//U8G2_SSD1305_128X64_RAYSTAR_1_4W_HW_SPI u8g2(U8G2_R0, /* cs=*/ 10, /* dc=*/ 9, /* reset=*/ 8);
//U8G2_SSD1309_128X64_NONAME0_1_4W_SW_SPI u8g2(U8G2_R0, /* clock=*/ 13, /* data=*/ 11, /* cs=*/ 10, /* dc=*/ 9, /* reset=*/ 8);  
//U8G2_SSD1309_128X64_NONAME0_1_4W_HW_SPI u8g2(U8G2_R0, /* cs=*/ 10, /* dc=*/ 9, /* reset=*/ 8);  
//U8G2_SSD1309_128X64_NONAME2_1_4W_SW_SPI u8g2(U8G2_R0, /* clock=*/ 13, /* data=*/ 11, /* cs=*/ 10, /* dc=*/ 9, /* reset=*/ 8);  
//U8G2_SSD1309_128X64_NONAME2_1_4W_HW_SPI u8g2(U8G2_R0, /* cs=*/ 10, /* dc=*/ 9, /* reset=*/ 8);  
//U8G2_SSD1316_128X32_1_4W_SW_SPI u8g2(U8G2_R0, /* clock=*/ 13, /* data=*/ 11, /* cs=*/ 10, /* dc=*/ 9, /* reset=*/ 8);  
//U8G2_SSD1316_128X32_1_4W_HW_SPI u8g2(U8G2_R0, /* cs=*/ 10, /* dc=*/ 9, /* reset=*/ 8); 	
//U8G2_SSD1316_96X32_1_4W_SW_SPI u8g2(U8G2_R0, /* clock=*/ 13, /* data=*/ 11, /* cs=*/ 10, /* dc=*/ 9, /* reset=*/ 8);  
//U8G2_SSD1316_96X32_1_4W_HW_SPI u8g2(U8G2_R0, /* cs=*/ 10, /* dc=*/ 9, /* reset=*/ 8); 	
//U8G2_SSD1317_96X96_1_4W_SW_SPI u8g2(U8G2_R0, /* clock=*/ 13, /* data=*/ 11, /* cs=*/ 10, /* dc=*/ 9, /* reset=*/ 8);  // not tested, not confirmed
//U8G2_SSD1317_96X96_1_4W_HW_SPI u8g2(U8G2_R0, /* cs=*/ 10, /* dc=*/ 9, /* reset=*/ 8); 	// not tested, not confirmed
//U8G2_SSD1318_128X96_1_4W_SW_SPI u8g2(U8G2_R0, /* clock=*/ 13, /* data=*/ 11, /* cs=*/ 10, /* dc=*/ 9, /* reset=*/ 8);  
//U8G2_SSD1318_128X96_1_4W_HW_SPI u8g2(U8G2_R0, /* cs=*/ 10, /* dc=*/ 9, /* reset=*/ 8); 	
//U8G2_SSD1320_160X132_1_4W_SW_SPI u8g2(U8G2_R0, /* clock=*/ 13, /* data=*/ 11, /* cs=*/ 10, /* dc=*/ 9, /* reset=*/ 8);  
//U8G2_SSD1320_160X132_1_4W_HW_SPI u8g2(U8G2_R0, /* cs=*/ 10, /* dc=*/ 9, /* reset=*/ 8); 	
//U8G2_SSD1320_160X80_1_4W_SW_SPI u8g2(U8G2_R0, /* clock=*/ 13, /* data=*/ 11, /* cs=*/ 10, /* dc=*/ 9, /* reset=*/ 8);  
//U8G2_SSD1320_160X80_1_4W_HW_SPI u8g2(U8G2_R0, /* cs=*/ 10, /* dc=*/ 9, /* reset=*/ 8); 	
//U8G2_LD7032_60X32_1_4W_SW_SPI u8g2(U8G2_R0, /* clock=*/ 11, /* data=*/ 12, /* cs=*/ 9, /* dc=*/ 10, /* reset=*/ 8);	// SW SPI Nano Board
//U8G2_LD7032_60X32_1_SW_I2C u8g2(U8G2_R0, /* clock=*/ 11, /* data=*/ 12, /* reset=*/ U8X8_PIN_NONE);	// NOT TESTED!
//U8G2_LD7032_60X32_ALT_1_4W_SW_SPI u8g2(U8G2_R0, /* clock=*/ 11, /* data=*/ 12, /* cs=*/ 9, /* dc=*/ 10, /* reset=*/ 8);	// SW SPI Nano Board
//U8G2_LD7032_60X32_ALT_1_SW_I2C u8g2(U8G2_R0, /* clock=*/ 11, /* data=*/ 12, /* reset=*/ U8X8_PIN_NONE);	// NOT TESTED!
//U8G2_LD7032_128X36_1_4W_SW_SPI u8g2(U8G2_R0, /* clock=*/ 11, /* data=*/ 12, /* cs=*/ 9, /* dc=*/ 10, /* reset=*/ 8);	// SW SPI Nano Board
//U8G2_LD7032_128X36_1_SW_I2C u8g2(U8G2_R0, /* clock=*/ 11, /* data=*/ 12, /* reset=*/ U8X8_PIN_NONE);	// NOT TESTED!
//U8G2_UC1701_EA_DOGS102_1_4W_SW_SPI u8g2(U8G2_R0, /* clock=*/ 13, /* data=*/ 11, /* cs=*/ 10, /* dc=*/ 9, /* reset=*/ 8);
//U8G2_UC1701_EA_DOGS102_1_4W_HW_SPI u8g2(U8G2_R0, /* cs=*/ 10, /* dc=*/ 9, /* reset=*/ 8);
//U8G2_PCD8544_84X48_1_4W_SW_SPI u8g2(U8G2_R0, /* clock=*/ 13, /* data=*/ 11, /* cs=*/ 10, /* dc=*/ 9, /* reset=*/ 8);	// Nokia 5110 Display
//U8G2_PCD8544_84X48_1_4W_HW_SPI u8g2(U8G2_R0, /* cs=*/ 10, /* dc=*/ 9, /* reset=*/ 8);						// Nokia 5110 Display
//U8G2_PCF8812_96X65_1_4W_SW_SPI u8g2(U8G2_R0, /* clock=*/ 13, /* data=*/ 11, /* cs=*/ 10, /* dc=*/ 9, /* reset=*/ 8);	// Could be also PCF8814
//U8G2_PCF8812_96X65_1_4W_HW_SPI u8g2(U8G2_R0, /* cs=*/ 10, /* dc=*/ 9, /* reset=*/ 8);						// Could be also PCF8814
//U8G2_PCF8812_101X64_1_4W_SW_SPI u8g2(U8G2_R0, /* clock=*/ 13, /* data=*/ 11, /* cs=*/ 10, /* dc=*/ 9, /* reset=*/ 8);	// Could be also PCF8814
//U8G2_PCF8812_101X64_1_4W_HW_SPI u8g2(U8G2_R0, /* cs=*/ 10, /* dc=*/ 9, /* reset=*/ 8);						// Could be also PCF8814
//U8G2_HX1230_96X68_1_3W_SW_SPI u8g2(U8G2_R0, /* clock=*/ 13, /* data=*/ 11, /* cs=*/ 10, /* reset=*/ 8);
//U8G2_HX1230_96X68_1_4W_SW_SPI u8g2(U8G2_R0, /* clock=*/ 13, /* data=*/ 11, /* cs=*/ 10, /* dc=*/ 9, /* reset=*/ 8);
//U8G2_KS0108_128X64_1 u8g2(U8G2_R0, 8, 9, 10, 11, 4, 5, 6, 7, /*enable=*/ 18, /*dc=*/ 17, /*cs0=*/ 14, /*cs1=*/ 15, /*cs2=*/ U8X8_PIN_NONE, /* reset=*/  U8X8_PIN_NONE); 	// Set R/W to low!
//U8G2_KS0108_ERM19264_1 u8g2(U8G2_R0, 8, 9, 10, 11, 4, 5, 6, 7, /*enable=*/ 18, /*dc=*/ 17, /*cs0=*/ 14, /*cs1=*/ 15, /*cs2=*/ 16, /* reset=*/  U8X8_PIN_NONE); 	// Set R/W to low!
//U8G2_HD44102_100X64_1 u8g2(U8G2_R0, 4, 5, 6, 7, 8, 9, 10, 11, /*enable=*/ 2, /*dc=*/ 3, /*cs0=*/ A0, /*cs1=*/ A1, /*cs2=*/ A2, /* reset=*/  U8X8_PIN_NONE); 	// Set R/W to low!
//U8G2_T7932_150X32_1 u8g2(U8G2_R0, 4, 5, 6, 7, 8, 9, 10, 11, /*enable=*/ 2, /*dc=*/ 3, /*cs0=*/ A0, /*cs1=*/ A1, /*cs2=*/ A2, /* reset=*/  U8X8_PIN_NONE); 	// Set R/W to low!
//U8G2_ST7920_256X32_1_8080 u8g2(U8G2_R0, 8, 9, 10, 11, 4, 5, 6, 7, /*enable=*/ 18, /*cs=*/ U8X8_PIN_NONE, /*dc=*/ 17, /*reset=*/ U8X8_PIN_NONE);
//U8G2_ST7920_256X32_1_SW_SPI u8g2(U8G2_R0, /* clock=*/ 18 /* A4 */ , /* data=*/ 16 /* A2 */, /* CS=*/ 17 /* A3 */, /* reset=*/ U8X8_PIN_NONE);
//U8G2_ST7920_192X32_1_8080 u8g2(U8G2_R0, 8, 9, 10, 11, 4, 5, 6, 7, /*enable=*/ 18, /*cs=*/ U8X8_PIN_NONE, /*dc=*/ 17, /*reset=*/ U8X8_PIN_NONE);
//U8G2_ST7920_192X32_1_SW_SPI u8g2(U8G2_R0, /* clock=*/ 18 /* A4 */ , /* data=*/ 16 /* A2 */, /* CS=*/ 17 /* A3 */, /* reset=*/ U8X8_PIN_NONE);
//U8G2_ST7920_128X32_1_8080 u8g2(U8G2_R0, 8, 9, 10, 11, 4, 5, 6, 7, /*enable=*/ 18, /*cs=*/ U8X8_PIN_NONE, /*dc=*/ 17, /*reset=*/ U8X8_PIN_NONE);
//U8G2_ST7920_128X32_1_SW_SPI u8g2(U8G2_R0, /* clock=*/ 18 /* A4 */ , /* data=*/ 16 /* A2 */, /* CS=*/ 17 /* A3 */, /* reset=*/ U8X8_PIN_NONE);
//U8G2_ST7920_144X32_1_8080 u8g2(U8G2_R0, 8, 9, 10, 11, 4, 5, 6, 7, /*enable=*/ 18, /*cs=*/ U8X8_PIN_NONE, /*dc=*/ 17, /*reset=*/ U8X8_PIN_NONE);
//U8G2_ST7920_144X32_1_SW_SPI u8g2(U8G2_R0, /* clock=*/ 18 /* A4 */ , /* data=*/ 16 /* A2 */, /* CS=*/ 17 /* A3 */, /* reset=*/ U8X8_PIN_NONE);
//U8G2_ST7920_160X32_1_8080 u8g2(U8G2_R0, 8, 9, 10, 11, 4, 5, 6, 7, /*enable=*/ 18, /*cs=*/ U8X8_PIN_NONE, /*dc=*/ 17, /*reset=*/ U8X8_PIN_NONE);
//U8G2_ST7920_160X32_1_SW_SPI u8g2(U8G2_R0, /* clock=*/ 18 /* A4 */ , /* data=*/ 16 /* A2 */, /* CS=*/ 17 /* A3 */, /* reset=*/ U8X8_PIN_NONE);
//U8G2_ST7920_128X64_1_8080 u8g2(U8G2_R0, 8, 9, 10, 11, 4, 5, 6, 7, /*enable=*/ 18 /* A4 */, /*cs=*/ U8X8_PIN_NONE, /*dc/rs=*/ 17 /* A3 */, /*reset=*/ 15 /* A1 */);	// Remember to set R/W to 0 
//U8G2_ST7920_128X64_1_SW_SPI u8g2(U8G2_R0, /* clock=*/ 18 /* A4 */ , /* data=*/ 16 /* A2 */, /* CS=*/ 17 /* A3 */, /* reset=*/ U8X8_PIN_NONE);
//U8G2_ST7920_128X64_1_SW_SPI u8g2(U8G2_R0, /* clock=*/ 13, /* data=*/ 11, /* CS=*/ 10, /* reset=*/ 8);
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
void loop(void) {
  u8g2_uint_t x;
  
  u8g2.firstPage();
  do {
  
    // draw the scrolling text at current offset
    x = offset;
    u8g2.setFont(u8g2_font_inb30_mr);		// set the target font
    do {								// repeated drawing of the scrolling text...
      u8g2.drawUTF8(x, 30, text);			// draw the scolling text
      x += width;						// add the pixel width of the scrolling text
    } while( x < u8g2.getDisplayWidth() );		// draw again until the complete display is filled
    
    u8g2.setFont(u8g2_font_inb16_mr);		// draw the current pixel width
    u8g2.setCursor(0, 58);
    u8g2.print(width);					// this value must be lesser than 128 unless U8G2_16BIT is set
    
  } while ( u8g2.nextPage() );
  
  offset-=1;							// scroll by one pixel
  if ( (u8g2_uint_t)offset < (u8g2_uint_t)-width )	
    offset = 0;							// start over again
    
  delay(10);							// do some small delay
}

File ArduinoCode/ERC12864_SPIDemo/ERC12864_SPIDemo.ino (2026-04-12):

//----------------------------------------------------------------------
// ERC12864_SPIDemo.ino
//
// Port of the ERC12864-11 tutorial demo (ERC12864-11-4SPI.c) to
// Arduino + U8g2. The original code targeted an STC12LE5A60S2 (8051)
// with bit-banged 4-wire SPI. Here, U8g2 handles SPI transport,
// display initialization, fonts, and drawing primitives.
//
// Target board: Adafruit QT Py ESP32-C3
// Display:      ERC12864-11 (ST7567, 128x64, 4-wire SPI)
// Libraries:    U8g2lib, SPI
//----------------------------------------------------------------------

#include <U8g2lib.h>
#include <SPI.h>

// --- Display constructor (matches other sketches in this project) ---
// Pin mapping for QT Py ESP32-C3:
//   clock = GPIO 10 (SCK)
//   data  = GPIO 7  (MO)
//   cs    = /CS tied to GND on breakout (display always selected)
//   dc    = GPIO 8  (MI, repurposed as A0/DC)
//   reset = GPIO 5  (SDA, repurposed)
// If sharing the SPI bus with other devices, connect /CS to a GPIO and replace U8X8_PIN_NONE.
U8G2_ST7565_ERC12864_ALT_F_4W_SW_SPI u8g2(U8G2_R0,
    /* clock=*/ 10, /* data=*/ 7, /* cs=*/ U8X8_PIN_NONE, /* dc=*/ 8, /* reset=*/ 5);

// --- Contrast (from tutorial: default EV level = 24) ---
uint8_t contrast = 24;

// // --- Contrast adjustment via buttons (uncomment and wire buttons) ---
// // BUTTON_UP_PIN:   GPIO 4 (A0) - connect a pushbutton to GND
// // BUTTON_DOWN_PIN: GPIO 9 (BOOT button on QT Py, active LOW)
// #define BUTTON_UP_PIN    4
// #define BUTTON_DOWN_PIN  9
//
// void setupButtons() {
//   pinMode(BUTTON_UP_PIN, INPUT_PULLUP);
//   pinMode(BUTTON_DOWN_PIN, INPUT_PULLUP);
// }
//
// // Ported from adj_Contrast() in the tutorial C code.
// // The original used raw SPI commands (0x81, value) with auto-repeat;
// // here we use u8g2.setContrast() and simple debounce.
// void adjustContrast() {
//   bool changed = false;
//   if (digitalRead(BUTTON_UP_PIN) == LOW) {
//     if (contrast < 63) contrast++;
//     changed = true;
//   }
//   if (digitalRead(BUTTON_DOWN_PIN) == LOW) {
//     if (contrast > 0) contrast--;
//     changed = true;
//   }
//   if (changed) {
//     u8g2.setContrast(contrast);
//     // Show current contrast value on display
//     u8g2.clearBuffer();
//     u8g2.setFont(u8g2_font_ncenB14_tr);
//     char buf[16];
//     snprintf(buf, sizeof(buf), "Contrast: %d", contrast);
//     u8g2.drawStr(0, 30, buf);
//     u8g2.sendBuffer();
//     delay(150);  // simple debounce
//   }
// }

// --- Sample XBM bitmap (16x16 smiley face) ---
// Demonstrates drawXBMP(), replacing the tutorial's DrawBMP(pic1..4).
#define SMILEY_WIDTH  16
#define SMILEY_HEIGHT 16
static const unsigned char smiley_xbm[] PROGMEM = {
  0xC0, 0x03, 0x30, 0x0C, 0x08, 0x10, 0x04, 0x20,
  0x04, 0x20, 0x22, 0x44, 0x22, 0x44, 0x02, 0x40,
  0x02, 0x40, 0x12, 0x48, 0x24, 0x24, 0xC4, 0x23,
  0x08, 0x10, 0x08, 0x10, 0x30, 0x0C, 0xC0, 0x03
};

//----------------------------------------------------------------------
// Demo 1: Text display
// Ports the tutorial's ShowString() calls with 16px and 8px fonts.
// The original showed Chinese characters on the top rows and ASCII
// strings below. We replace the Chinese text with a title screen.
//----------------------------------------------------------------------
void demoText() {
  u8g2.clearBuffer();

  // Large font — replaces SIZE=16 / ShowString()
  u8g2.setFont(u8g2_font_ncenB14_tr);
  u8g2.drawStr(4, 16, "ERC12864-11");

  // Medium font — replaces SIZE=8 / ShowString()
  u8g2.setFont(u8g2_font_6x10_tr);
  u8g2.drawStr(4, 32, "ST7567 SPI Demo");
  u8g2.drawStr(4, 44, "U8g2 + ESP32-C3");
  u8g2.drawStr(4, 56, "Hello World!");

  u8g2.sendBuffer();
  delay(2000);
}

//----------------------------------------------------------------------
// Demo 2: Graphics primitives
// Demonstrates the drawing functions that replace the tutorial's
// direct page/column writes.
//----------------------------------------------------------------------
void demoGraphics() {
  u8g2.clearBuffer();

  // Filled rectangle (drawBox)
  u8g2.drawBox(4, 4, 24, 24);

  // Hollow rectangle (drawFrame)
  u8g2.drawFrame(34, 4, 24, 24);

  // Rounded box
  u8g2.drawRBox(64, 4, 28, 24, 6);

  // Circle (outline)
  u8g2.drawCircle(16, 48, 12, U8G2_DRAW_ALL);

  // Disc (filled circle)
  u8g2.drawDisc(46, 48, 12, U8G2_DRAW_ALL);

  // Triangle
  u8g2.drawTriangle(68, 60, 78, 34, 88, 60);

  // Lines
  u8g2.drawLine(96, 4, 124, 60);
  u8g2.drawLine(96, 60, 124, 4);

  u8g2.sendBuffer();
  delay(2000);
}

//----------------------------------------------------------------------
// Demo 3: Bitmap display
// Ports the concept of DrawBMP(pic1..4) from the tutorial.
// The original showed 4 full-screen bitmaps; here we show one small
// XBM bitmap tiled/centered to demonstrate drawXBMP().
//----------------------------------------------------------------------
void demoBitmap() {
  u8g2.clearBuffer();

  u8g2.setFont(u8g2_font_6x10_tr);
  u8g2.drawStr(0, 10, "XBM Bitmap Demo:");

  // Draw the smiley at several positions
  u8g2.drawXBMP(8, 20, SMILEY_WIDTH, SMILEY_HEIGHT, smiley_xbm);
  u8g2.drawXBMP(32, 20, SMILEY_WIDTH, SMILEY_HEIGHT, smiley_xbm);
  u8g2.drawXBMP(56, 20, SMILEY_WIDTH, SMILEY_HEIGHT, smiley_xbm);
  u8g2.drawXBMP(80, 20, SMILEY_WIDTH, SMILEY_HEIGHT, smiley_xbm);
  u8g2.drawXBMP(104, 20, SMILEY_WIDTH, SMILEY_HEIGHT, smiley_xbm);

  // Draw a larger version using the same bitmap at bottom
  u8g2.drawXBMP(56, 44, SMILEY_WIDTH, SMILEY_HEIGHT, smiley_xbm);

  u8g2.sendBuffer();
  delay(2000);
}
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

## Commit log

2026-03-04 Initial Commit of COG breakout board with SPI interface
    [COGDisplayBreakout.kicad_pcb, COGDisplayBreakout.kicad_sch]
2026-03-25 3rd Rev send to OshPark
    [COGDisplayBreakout.kicad_pcb, COGDisplayBreakout.kicad_sch]
2026-03-26 Adds a footprint and symbol for the ERC12864FSF-11
2026-04-02 Notes on the v0.2 boards
    [COGDisplayBreakout-copy.kicad_pcb]
2026-04-02 Adds a case based on v0.2 board outline
2026-04-02 Adds the gerbers for v0.2 and some example code
    [COGDisplayBreakout-CaseV1.step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]
2026-04-02 Fixes v0.2 problems, new symbol and 3D model
    [COGDisplayBreakout.kicad_pcb, COGDisplayBreakout.kicad_sch, ERC12864FSF-11.step]
2026-04-03 Rewired LED: fix A/K swap and adds control from pin 6
    [COGDisplayBreakout.kicad_pcb, COGDisplayBreakout.kicad_sch]
2026-04-03 Sent to fab 04/03/2026
    [COGDisplayBreakout-B_Adhesive.gbr, COGDisplayBreakout-B_Courtyard.gbr, COGDisplayBreakout-B_Cu.gbr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]
2026-04-04 Ensure Handsolder 0805 footprints
    [COGDisplayBreakout.kicad_pcb, COGDisplayBreakout.kicad_sch, COGDisplayBreakout.step]
2026-04-04 readme edits
    [COGDisplayBreakout-CaseV1.step, COGDisplayBreakout.kicad_pcb, COGDisplayBreakout.kicad_sch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]
2026-04-04 Fixes head pin names and adds some links
2026-04-04 Adds a screen grab of schematic and PCB
2026-04-04 Readme edits and directory cleanup
    [COGDisplayBreakout-copy.kicad_pcb]
2026-04-08 Adds a 3D model of a bezel
    [COGDisplayBreakout-Bezel.step, COGDisplayBreakout-Bezel.stl, COGDisplayBreakout.kicad_sch]
2026-04-12 Removes /CS line (tied low) from test code
    [COGDisplayBreakout-Case.step]
2026-04-12 Adds power on reset
    [COGDisplayBreakout.kicad_pcb, COGDisplayBreakout.kicad_sch]
2026-04-16 new board layout for power-on reset
    [COGDisplayBreakout-B_Adhesive.gbr, COGDisplayBreakout-B_Courtyard.gbr, COGDisplayBreakout-B_Cu.gbr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]
2026-04-16 Power-on reset info for readme
2026-04-18 Removes FFC slot (NPTH) from drillings
    [COGDisplayBreakout.kicad_pcb]
2026-05-18 Adds a SN field and label text, v1.2
    [COGDisplayBreakout-B_Adhesive.gbr, COGDisplayBreakout-B_Courtyard.gbr, COGDisplayBreakout-B_Cu.gbr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]
